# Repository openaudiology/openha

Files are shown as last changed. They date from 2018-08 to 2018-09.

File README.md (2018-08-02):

# Project

This project provides the source files for a hearing aid device that can be used as a tool for embedded digital signal processing.
It is based on a Cortex M4 chip, with BLE and USB interfaces.

This project is supported by the non-profit organisation [Open Audiology](https://www.openaudiology.org) (French: Association loi 1901).

## Contents

The repository currently contains hardware and documentation files. The project is under active development with a targeted release in the Fall of 2018.

## Built With

* [Eagle CAD](https://www.autodesk.com/products/eagle/overview) - For electronic circuits and board routing.
* [Fusion 360](https://www.autodesk.com/products/fusion-360/overview) - 3D models

## Authors

* **Victor Benichoux** - *electronics* - Hearing researcher at [Institut Pasteur](https://research.pasteur.fr/en/member/victor-benichoux/). Contact me if you are interested in this project.
* **Grégory Gérenton** - *electronics* - Open Audiology.

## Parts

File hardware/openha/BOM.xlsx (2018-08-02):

Part | Manufacturer reference | Package | Name | Link | Reference digi-key
microcontroller | STM32L476xx | WLCSP72 | U1 | http://www.st.com/en/microcontrollers/stm32l476rg.html
bluetooth | BlueNRG-MS | WLCSP34 |  | http://www.st.com/en/wireless-connectivity/bluenrg-ms.html | 497-15381-1-ND
balun | BALF-NRG-01D3 | Flip chip 4 |  | http://www.st.com/en/emi-filtering-and-signal-conditioning/balf-nrg-01d3.html
codec | PCM1774 | WLCSP |  | http://www.ti.com/product/PCM1774/description
voltage regulator | LD39115J | Flip chip 4 |  | http://www.st.com/en/power-management/ld39115j.html
 | LDK130
ESD protection | USBLC6-2
Battery charger | STBC08
MEMS microphone | mp34dt05-a |  |  | http://www.st.com/content/st_com/en/search.html#q=mems%20microphone-t=products-page=1
 | LDK120M
Gas gauge | STC3115 | CSP |  | https://www.st.com/en/power-management/stc3115.html
Connector? | BM23FR0.6-6DS-0.35V

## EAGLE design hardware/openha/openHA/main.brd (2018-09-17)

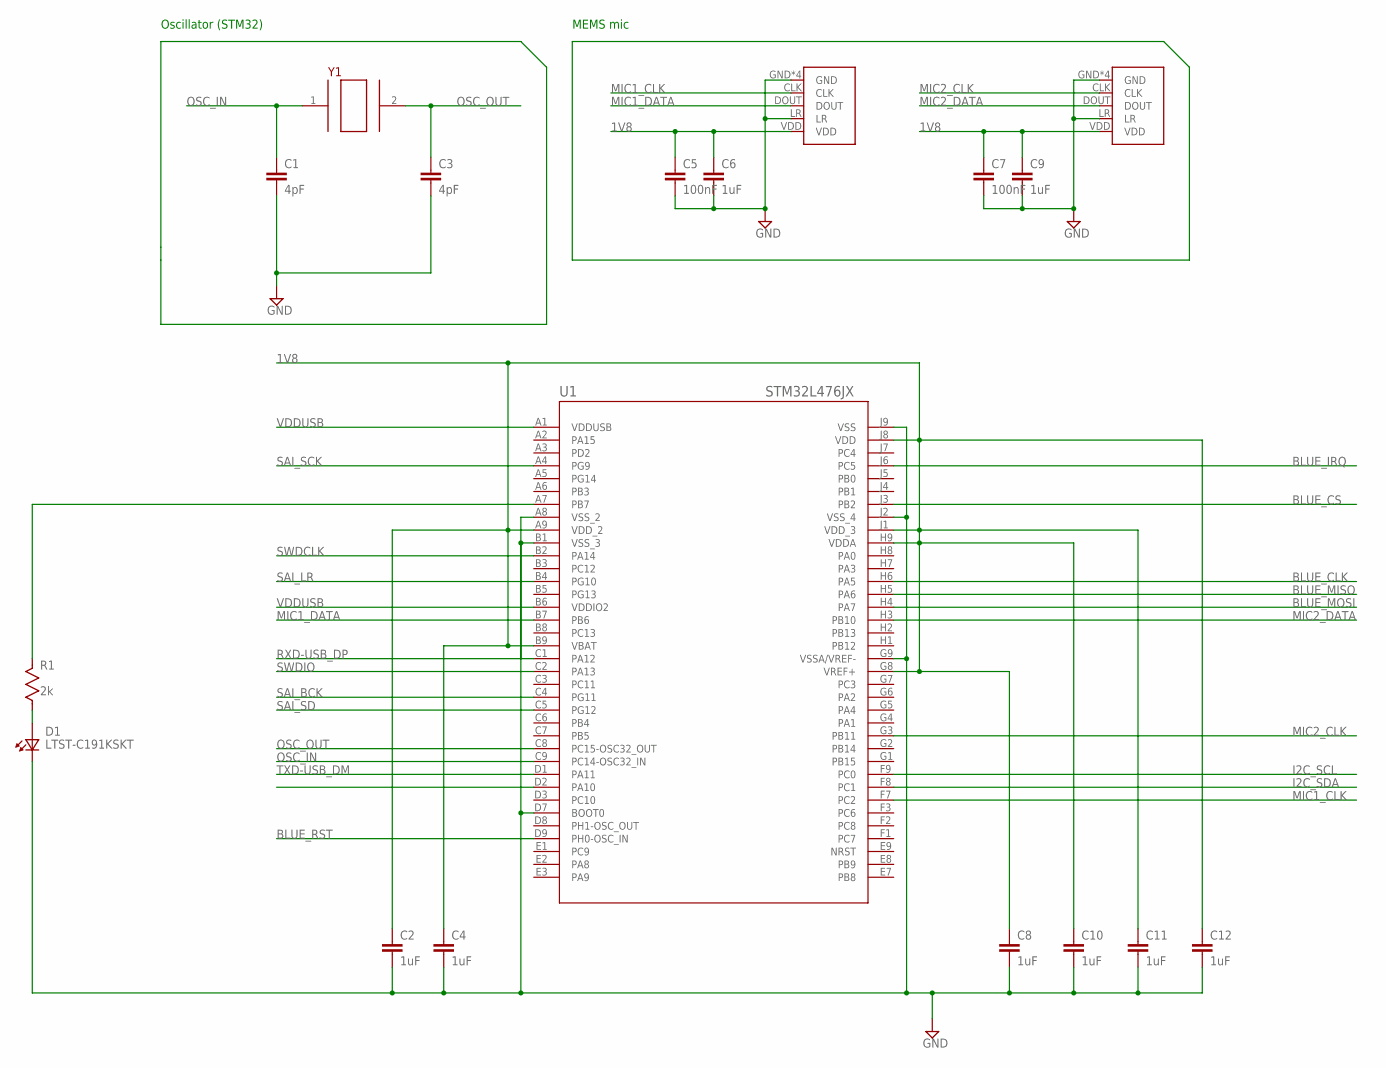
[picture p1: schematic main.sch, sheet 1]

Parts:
C1, C3: 4pF; CAPC0603X30
C2, C4, C6, C8, C9, C10, C11, C12: 1uF; CAPC0603X30
C5, C7: 100nF; CAPC0603X30
D1: LTST-C191KSKT; 0603
R1: 2k; CAPC0603X30
U1: STM32L476JX; WLCSP72
U2, U3: MP34DT05-A; MIC-PACK
Y1: ABS06-107SMT; CAPC2215X70

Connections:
1V8: C2.1, C4.1, C5.1, C6.1, C7.1, C8.1, C9.1, C10.1, C11.1, C12.1, U1.A9 (VDD_2), U1.B9 (VBAT), U1.G8 (VREF+), U1.H9 (VDDA), U1.J1 (VDD_3), U1.J8 (VDD), U2.VDD, U3.VDD; also elsewhere on the board
BLUE_CLK: U1.H6 (PA5); also elsewhere on the board
BLUE_CS: U1.J3 (PB2); also elsewhere on the board
BLUE_IRQ: U1.J6 (PC5); also elsewhere on the board
BLUE_MISO: U1.H5 (PA6); also elsewhere on the board
BLUE_MOSI: U1.H4 (PA7); also elsewhere on the board
BLUE_RST: U1.D9 (PH0-OSC_IN)
GND: C1.2, C2.2, C3.2, C4.2, C5.2, C6.2, C7.2, C8.2, C9.2, C10.2, C11.2, C12.2, D1.1 (K2), U1.A8 (VSS_2), U1.B1 (VSS_3), U1.D7 (BOOT0), U1.G9 (VSSA/VREF-), U1.J2 (VSS_4), U1.J9 (VSS), U2.GND, U2.GND1 (GND), U2.GND2 (GND), U2.GND3 (GND), U2.LR, U3.GND, U3.GND1 (GND), U3.GND2 (GND), U3.GND3 (GND), U3.LR; also elsewhere on the board
I2C_SCL: U1.F9 (PC0); also elsewhere on the board
I2C_SDA: U1.F8 (PC1); also elsewhere on the board
MIC1_CLK: U1.F7 (PC2), U2.CLK
MIC1_DATA: U1.B7 (PB6), U2.DOUT
MIC2_CLK: U1.G3 (PB11), U3.CLK
MIC2_DATA: U1.H3 (PB10), U3.DOUT
unnamed: R1.1, U1.A7 (PB7)
unnamed: D1.2 (A2), R1.2
OSC_IN: C1.1, U1.C9 (PC14-OSC32_IN), Y1.1
OSC_OUT: C3.1, U1.C8 (PC15-OSC32_OUT), Y1.2
RXD-USB_DP: U1.C1 (PA12); also elsewhere on the board
SAI_BCK: U1.C4 (PG11); also elsewhere on the board
SAI_LR: U1.B4 (PG10); also elsewhere on the board
SAI_SCK: U1.A4 (PG9); also elsewhere on the board
SAI_SD: U1.C5 (PG12); also elsewhere on the board
SWDCLK: U1.B2 (PA14); also elsewhere on the board
SWDIO: U1.C2 (PA13); also elsewhere on the board
TXD-USB_DM: U1.D1 (PA11); also elsewhere on the board
VDDUSB: U1.A1 (VDDUSB), U1.B6 (VDDIO2); also elsewhere on the board

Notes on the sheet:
Oscillator (STM32)
MEMS mic

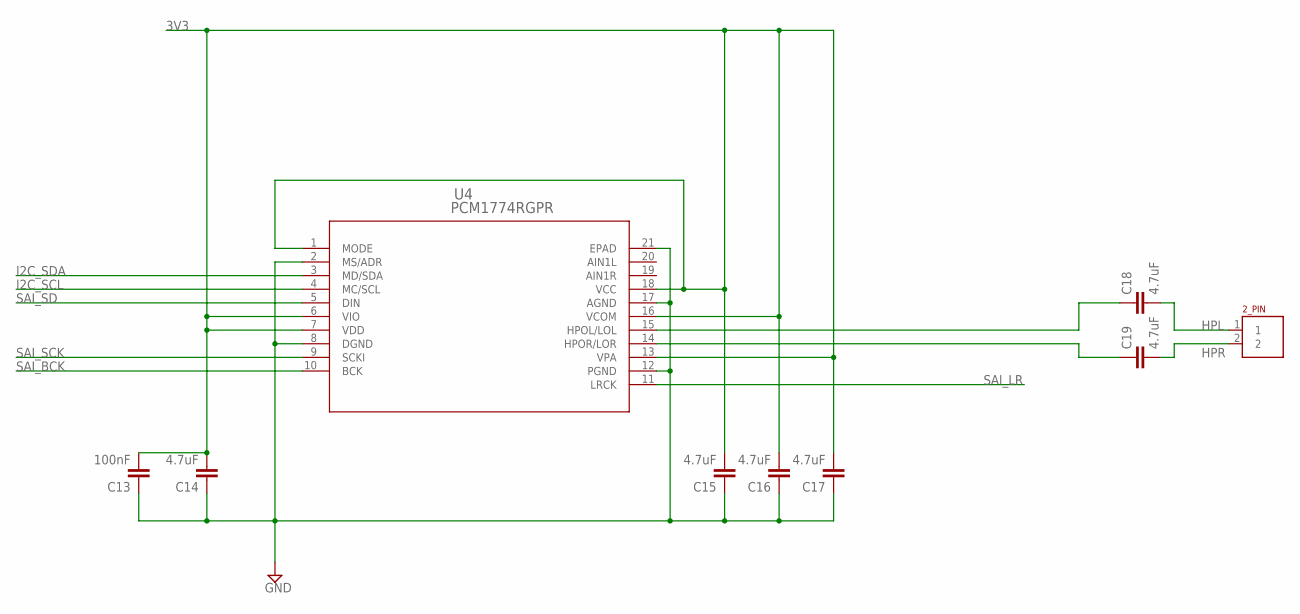
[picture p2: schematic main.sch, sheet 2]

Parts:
C13: 100nF; CAPC0603X30
C14, C15, C16, C17, C18, C19: 4.7uF; CAPC0603X30
J1: 2PIN; 2PINCON
U4: PCM1774RGPR; RGP20_2P7X2P7

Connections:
3V3: C13.2, C14.2, C15.2, C16.2, C17.2, U4.1 (MODE), U4.6 (VIO), U4.7 (VDD), U4.13 (VPA), U4.16 (VCOM), U4.18 (VCC); also elsewhere on the board
GND: C13.1, C14.1, C15.1, C16.1, C17.1, U4.2 (MS/ADR), U4.8 (DGND), U4.12 (PGND), U4.17 (AGND), U4.21 (EPAD); also elsewhere on the board
HPL: C18.2, J1.1
HPR: C19.2, J1.2
I2C_SCL: U4.4 (MC/SCL); also elsewhere on the board
I2C_SDA: U4.3 (MD/SDA); also elsewhere on the board
unnamed: C18.1, U4.15 (HPOL/LOL)
unnamed: C19.1, U4.14 (HPOR/LOR)
SAI_BCK: U4.10 (BCK); also elsewhere on the board
SAI_LR: U4.11 (LRCK); also elsewhere on the board
SAI_SCK: U4.9 (SCKI); also elsewhere on the board
SAI_SD: U4.5 (DIN); also elsewhere on the board

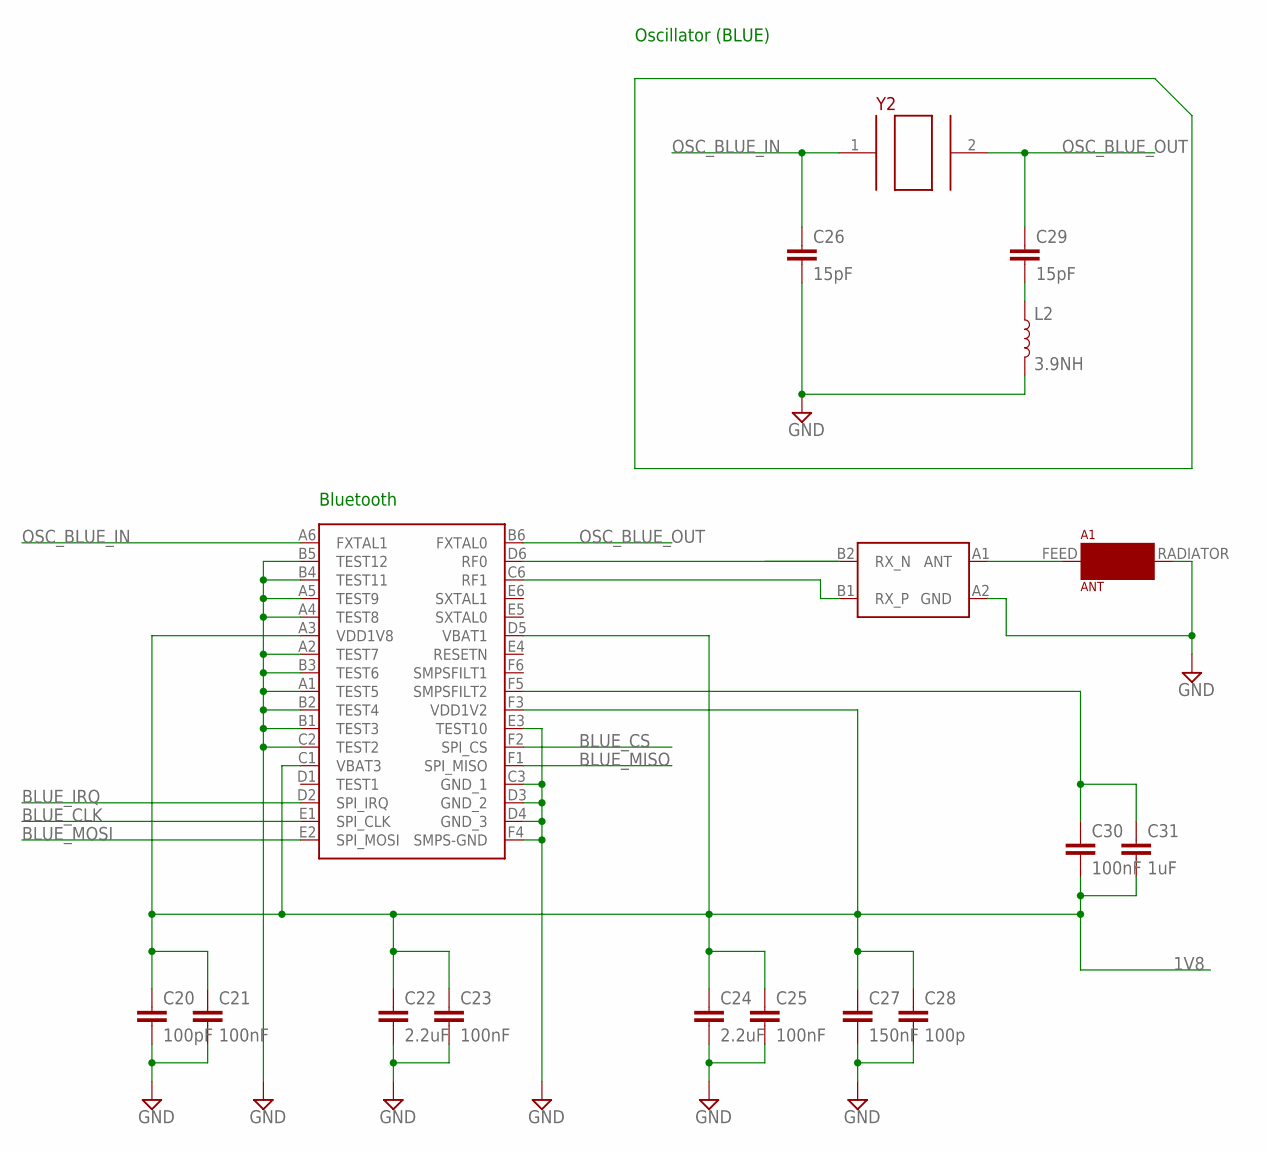
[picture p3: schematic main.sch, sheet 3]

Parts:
A1: ANT; ANTPACK
C20: 100pF; CAPC0603X30
C21, C23, C25, C30: 100nF; CAPC0603X30
C22, C24: 2.2uF; CAPC0603X30
C26, C29: 15pF; CAPC0603X30
C27: 150nF; CAPC0603X30
C28: 100p; CAPC0603X30
C31: 1uF; CAPC0603X30
L1: BALF-NRG-01D3; FLIPCHIP
L2: 3.9NH; 0402
U5: BLUENRG-MS; WLCSP34
Y2: ABS06-107SMT; CAPC2215X70

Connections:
1V8: C20.1, C21.1, C22.1, C23.1, C24.1, C25.1, C27.1, C28.1, C30.2, C31.2, U5.A3 (VDD1V8), U5.C1 (VBAT3), U5.D5 (VBAT1), U5.F3 (VDD1V2); also elsewhere on the board
BLUE_CLK: U5.E1 (SPI_CLK); also elsewhere on the board
BLUE_CS: U5.F2 (SPI_CS); also elsewhere on the board
BLUE_IRQ: U5.D2 (SPI_IRQ); also elsewhere on the board
BLUE_MISO: U5.F1 (SPI_MISO); also elsewhere on the board
BLUE_MOSI: U5.E2 (SPI_MOSI); also elsewhere on the board
GND: A1.RADIATOR, C20.2, C21.2, C22.2, C23.2, C24.2, C25.2, C26.2, C27.2, C28.2, L1.A2 (GND), L2.2, U5.A1 (TEST5), U5.A2 (TEST7), U5.A4 (TEST8), U5.A5 (TEST9), U5.B1 (TEST3), U5.B2 (TEST4), U5.B3 (TEST6), U5.B4 (TEST11), U5.B5 (TEST12), U5.C2 (TEST2), U5.C3 (GND_1), U5.D3 (GND_2), U5.D4 (GND_3), U5.E3 (TEST10), U5.F4 (SMPS-GND); also elsewhere on the board
unnamed: C29.2, L2.1
unnamed: A1.FEED, L1.A1 (ANT)
unnamed: L1.B1 (RX_P), U5.C6 (RF1)
unnamed: L1.B2 (RX_N), U5.D6 (RF0)
unnamed: C30.1, C31.1, U5.F5 (SMPSFILT2)
OSC_BLUE_IN: C26.1, U5.A6 (FXTAL1), Y2.1
OSC_BLUE_OUT: C29.1, U5.B6 (FXTAL0), Y2.2
RESETN: U5.E4 (RESETN)
SMPSFILT1: U5.F6 (SMPSFILT1)
SXTAL0: U5.E5 (SXTAL0)
SXTAL1: U5.E6 (SXTAL1)
TEST1: U5.D1 (TEST1)

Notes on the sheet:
Bluetooth
Oscillator (BLUE)

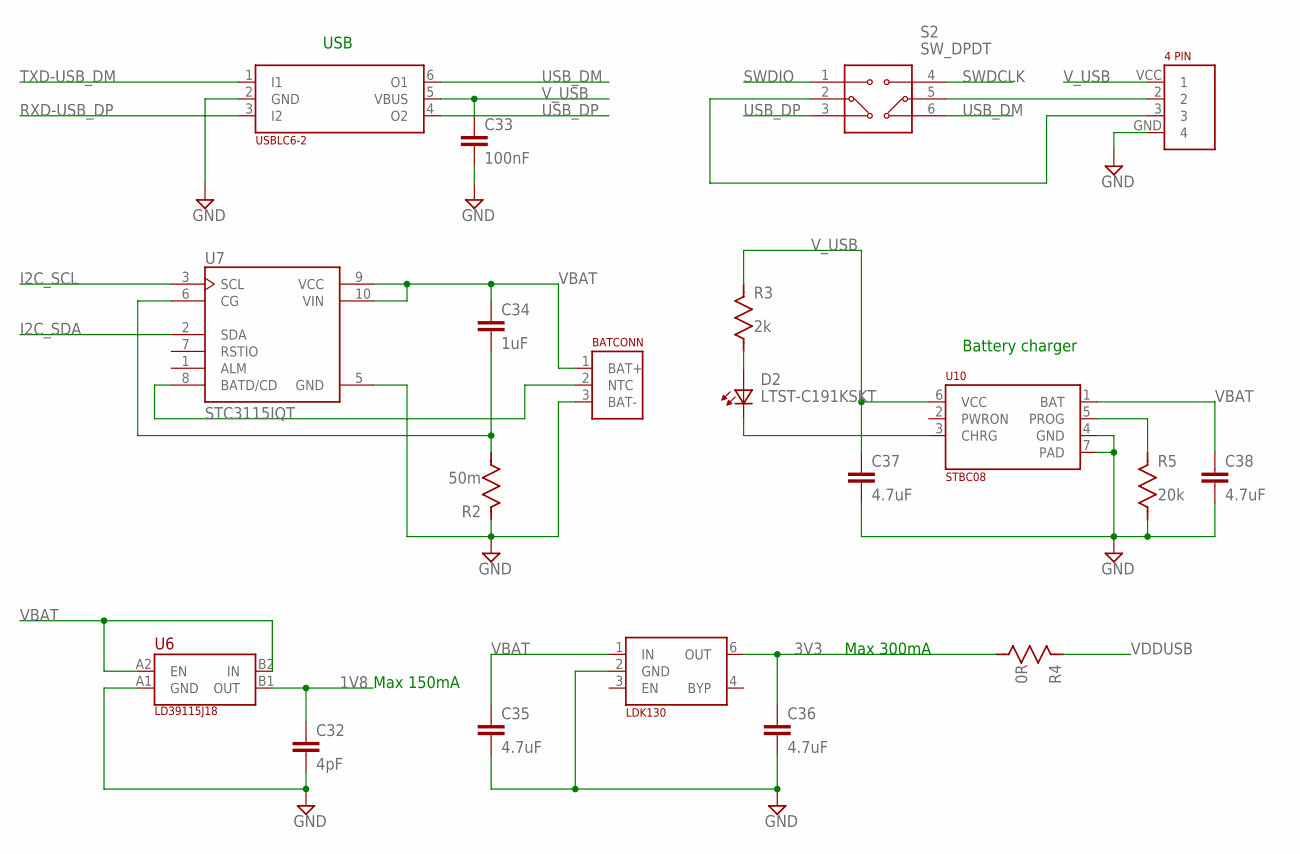
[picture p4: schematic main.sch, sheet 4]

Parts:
C32: 4pF; CAPC0603X30
C33: 100nF; CAPC0603X30
C34: 1uF; CAPC0603X30
C35, C36, C37, C38: 4.7uF; CAPC0603X30
D2: LTST-C191KSKT; 0603
J2: BATT; BATCONN
J3: CS44
R2: 50m; CAPC0603X30
R3: 2k; CAPC0603X30
R4: 0R; CAPC0603X30
R5: 20k; CAPC0603X30
S2: SW_DPDT
U6: LD39115J18; FLIPCHIP-2
U7: STC3115IQT; SON50P300X200X60-10N
U8: USBLC6-2; SOT-666
U9: LDK130; DFN6
U10: STBC08; DFN6

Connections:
1V8: C32.1, U6.B1 (OUT); also elsewhere on the board
3V3: C36.1, R4.2, U9.6 (OUT); also elsewhere on the board
BAT_NTC: J2.2 (NTC), U7.8 (BATD/CD)
CHRG: D2.1 (K2), U10.3 (CHRG)
GND: C32.2, C33.2, C35.2, C36.2, C37.2, C38.2, J2.3 (BAT-), J3.GND (4), R2.1, R5.2, U6.A1 (GND), U7.5 (GND), U8.2 (GND), U9.2 (GND), U10.4 (GND), U10.7 (PAD); also elsewhere on the board
I2C_SCL: U7.3 (SCL); also elsewhere on the board
I2C_SDA: U7.2 (SDA); also elsewhere on the board
unnamed: D2.2 (A2), R3.2
unnamed: C34.2, R2.2, U7.6 (CG)
unnamed: R5.1, U10.5 (PROG)
unnamed: J3.2, S2.5
unnamed: J3.3, S2.2
RXD-USB_DP: U8.3 (I2); also elsewhere on the board
SWDCLK: S2.4; also elsewhere on the board
SWDIO: S2.1; also elsewhere on the board
TXD-USB_DM: U8.1 (I1); also elsewhere on the board
USB_DM: S2.6, U8.6 (O1)
USB_DP: S2.3, U8.4 (O2)
VBAT: C34.1, C35.1, C38.1, J2.1 (BAT+), U6.A2 (EN), U6.B2 (IN), U7.9 (VCC), U7.10 (VIN), U9.1 (IN), U10.1 (BAT)
VDDUSB: R4.1; also elsewhere on the board
V_USB: C33.1, C37.1, J3.VCC (1), R3.1, U8.5 (VBUS), U10.6 (VCC)

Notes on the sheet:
Battery charger
USB
Max 300mA
Max 150mA

Board: 2 copper layers, 64 parts (3 on the bottom side), 49 nets, no tracks yet.

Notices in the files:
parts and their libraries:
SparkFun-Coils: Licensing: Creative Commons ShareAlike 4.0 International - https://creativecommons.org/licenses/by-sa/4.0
